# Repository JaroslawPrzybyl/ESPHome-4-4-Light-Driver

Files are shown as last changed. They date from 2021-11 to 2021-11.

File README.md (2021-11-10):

# ESPHome-4-4-Light-Driver
**Small light controller with 4 AC SSR outputs and 4 optoisolated inputs, designed for Home Assistant.**

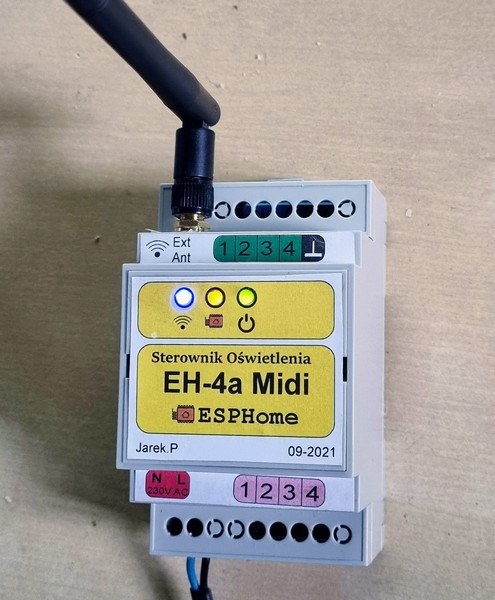
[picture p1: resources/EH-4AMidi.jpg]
EH-4A Midi

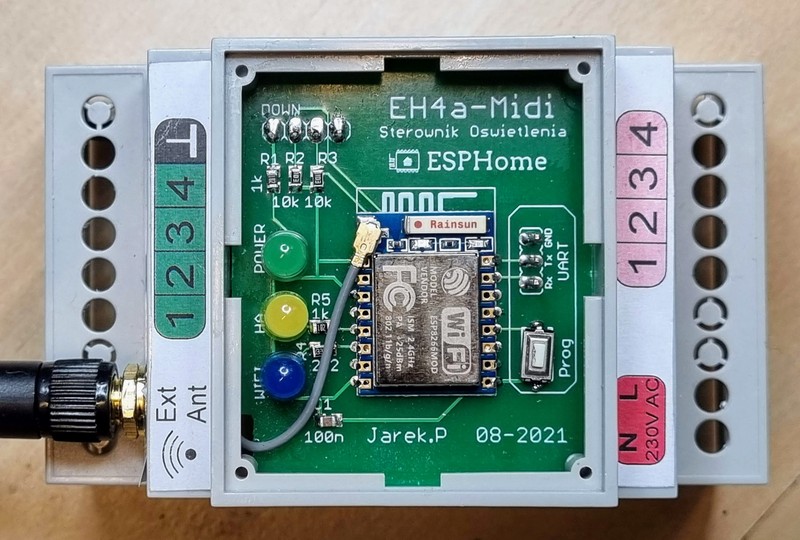
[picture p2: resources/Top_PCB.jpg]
Upper board

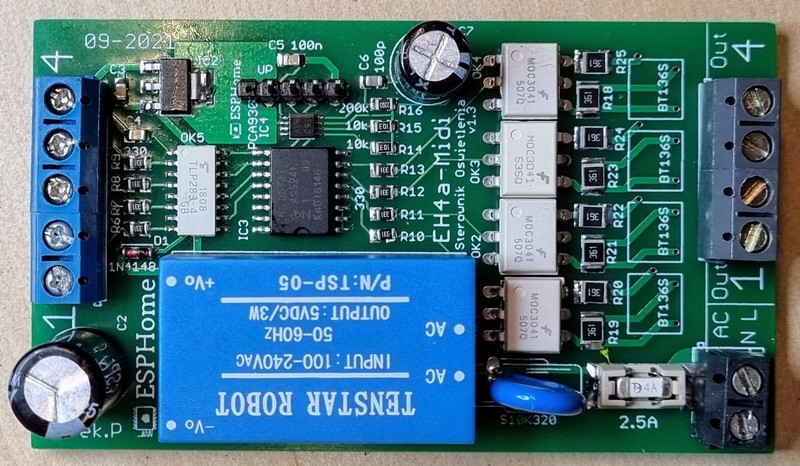
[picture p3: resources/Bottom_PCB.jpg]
Main board


## Design
Not so much to describe - just ESP with power supply and I2C expander, where four ports are used as inputs and four as outputs. Design of inputs and outputs was using by me from a years with other Home Automation systems (old stuff based on AVR CPUs, currently swapping by a bit more modern, HomeAssistant compatible devices), without any problems.  
Outputs are made as SSR relays, switched with zero-cross detection. It means safe switching of any active  load like lamps, etc, but reactive load is not allowed here, so please don't use this device with any induction load, like e.g. engines.   
Inputs are designed for use momentary buttons, each input port responds to shorting it with the COM. Needed wiring of inputs (and outputs) is shown on schematic diagram, with grey lines.  

**WARNING! Don't connect input lines with AC installation or any external power lines, it must be fully separated, only direct connections to switch buttons are allowed**   

## Parts and components
Base of this device is an ESP-07 module, choosen due to possibility to connect external antenna. If it is not needed, can be used also ESP12 or any other with the same footprint, such change has be included in the code.
All other components are listed in BoM file.   

Connection between boards can be done by any method, pins have to be connected 1:1.   
Because reverse connection will damage ESP module, I would recommend to use any connection method, which avoid of it. Connector like  Molex KK would be the best solution, any other with raster 2,54 will be also ok. On my prototype I used ordinary goldpin connector with one pin more than needed, this pin is removed and corresponding pin in the plug is blinded by glue.

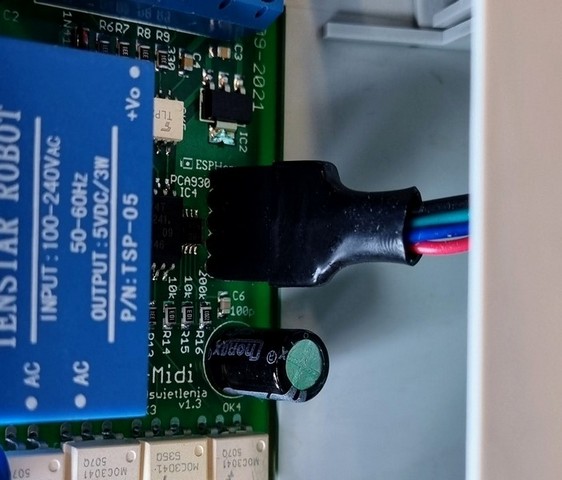
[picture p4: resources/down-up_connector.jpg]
Connector


PSU: popular chinese HLK-PM01, 5V/0.6A. AC input is protected by varistor and 4A fuse. Due to lack of space I used small fuse SMD 1808 which is not recommended to use with voltage higher than 127V - I know, but I ignored it, because this part really suited me and here important for me was to have something able to make a break in the circuit. Load will be (should be!) active, so there shouldn't be a problems with overvoltage, arcs etc. Fuse is changeable, fuses and sockets were bought on Aliexpress:

https://www.aliexpress.com/item/32840204422.html

Terminal ports - I used old spare, which I had in my draver, but any with raster 5.08mm can be used here. Or - if needed, popular "green" sepparable Phoenix terminal blocks should fit here also.

## Assembly

PCB Gerber files are attached. It is not exactly the same version as shown on photos, it was a prototype, after I did some cosmetic corrections and here I put a final version.  
Both PCBs are prepared for standard DIN rail box case Gainta D3MG http://www.gainta.com/en/d3mg.html, nothing more is needed for assembly, both PCBs fit into the latches inside the case.    
External antena is optional, you can use it or stay with internal - up to you. When device is mounted inside of metal switchbox, external antenna mounted outside of box is strongly recommended.  
Stickers should be printed on self-adhesive paper or foil. In my projects I'm using self-adhesive printable white or silver foil, special for laser printers.   

## Software

From ESP-Home perspective it is really simple device, shouldn't be any problems with the code. The only important thing which should be pointed out is that when you use ESP-07, its integration in ESPHome contains a bug, which is not corrected from the years (was reported many times as I know, without any result). So in declaration of board type, instead of esp_07, has to be used esp01_1m and with this workaround everything works fine.  
Basic proposal of code is added into the files, each input controls its corresponding output, where "short" click on the button just switch on or off the output, "long" click (press and hold more than 1s) switches off all outputs (really useful option for fast switching off the lights in the room). Clicks shorter than 50ms are ignored (debouncing), longer than 5s are also ignored (could be additionally reported as a short circuit on the line, it is not included in this code, but can be simply done).   
Only line 4 works a bit different, here is implemented a timer: short click switches on Out4  for 30 seconds (time value is set as at the top of code), after this time output  will be switched off. Each time it can be switched off manually by click the button again. And long click here works differently: it switches on the output permanently (until switching off by pressing button). 

Exemplary entity works with this code (entity code added into files):

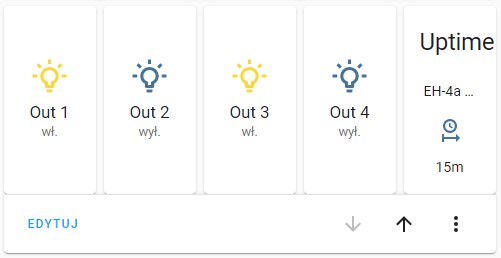
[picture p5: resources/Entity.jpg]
Entity


##  



Shield: [][cc-by-nc-sa]

This work is licensed under a
[Creative Commons Attribution-NonCommercial-ShareAlike 4.0 International License][cc-by-nc-sa].

[][cc-by-nc-sa]

[cc-by-nc-sa]: http://creativecommons.org/licenses/by-nc-sa/4.0/
[cc-by-nc-sa-image]: https://licensebuttons.net/l/by-nc-sa/4.0/88x31.png
[cc-by-nc-sa-shield]: https://img.shields.io/badge/License-CC%20BY--NC--SA%204.0-lightgrey.svg

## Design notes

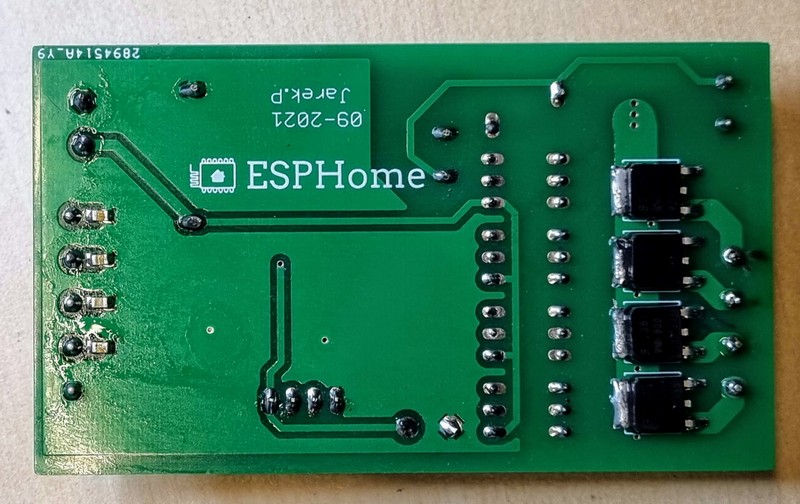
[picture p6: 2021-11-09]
resources/Triacs.jpg

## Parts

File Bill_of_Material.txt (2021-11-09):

Part    Value   Device               Package            Description
C1      100n    C-EUC0805            C0805
C2      470u    CPOL-EUE3.5-8        E3,5-8
C3      100n    C-EUC0805            C0805
C4      100n    C-EUC0805            C0805
C5      100n    C-EUC0805            C0805
C6      100p    C-EUC0805            C0805
C7      220u    CPOL-EUE2.5-7        E2,5-7
C100    100n    C-EUC0805            C0805
C101    100n    C-EUC0805            C0805
C102    100n    C-EUC0805            C0805
C103    100n    C-EUC0805            C0805
D1      1N5819  DIODESOD-123         SOD-123            Can be any other Shottky.
DOWN            PINHD-1X4            1X04               PIN HEADER
F1      4A      2920L700SL           2920L              SMD1808 fuse socket with fuse 4A
HA              LED3MM               LED3MM             LED 5mm Orange
IC1     ESP8266-ESP-07               ESP12              ESP8266 Wifi module
IC2     LD117A  LD117AS12TR          SOT223
IC3     PCF8574TPCF8574T             SO16W
IC4     PCA9306 IC2_LEVEL_TRANSLATER MSOP08
OK1     MOC3041 IL420                DIL06
OK2     MOC3041 IL420                DIL06
OK3     MOC3041 IL420                DIL06
OK4     MOC3041 IL420                DIL06
OK5     TLP283-4TLP283-4             MINI-FLAT-16
POWER           LED3MM               LED3MM             LED 5mm Green
R1      820     R-EU_M0805           M0805
R2      10k     R-EU_M0805           M0805
R3      10k     R-EU_M0805           M0805
R4      3k3     R-EU_M0805           M0805
R5      820     R-EU_M0805           M0805
R6      330     R-EU_M0805           M0805
R7      330     R-EU_M0805           M0805
R8      330     R-EU_M0805           M0805
R9      330     R-EU_M0805           M0805
R10     330     R-EU_M0805           M0805
R11     330     R-EU_M0805           M0805
R12     330     R-EU_M0805           M0805
R13     330     R-EU_M0805           M0805
R14     10k     R-EU_R0805           R0805
R15     10k     R-EU_R0805           R0805
R16     200k    R-EU_R0805           R0805
R17     S10K300 S10K300              S10K300            VARISTOR
R18     330     R-EU_R1210           R1210
R19     330     R-EU_R1210           R1210
R20     360     R-EU_R1210           R1210
R21     330     R-EU_R1210           R1210
R22     360     R-EU_R1210           R1210
R23     330     R-EU_R1210           R1210
R24     360     R-EU_R1210           R1210
R25     360     R-EU_R1210           R1210
S1      Prog    DTSM-3               DTSM-3				SMD mountable tact switch
T100    BT136S  ACT108WDPAK          SOT428
T101    BT136S  ACT108WDPAK          SOT428
T102    BT136S  ACT108WDPAK          SOT428
T103    BT136S  ACT108WDPAK          SOT428
U1      HLK-05PMHLK-PM01_HLK-PM01    HLK-PM01_HLK-PM01  HLK-PM05
UART            JP2E                 JP2                JUMPER
UP              PINHD-1X4            1X04               PIN HEADER
WIFI            LED3MM               LED3MM             LED 5mm Blue
X1      MKDSN1,5MKDSN1,5/5-5,08      MKDSN1,5/5-5,08
X2      230V AC MKDSN1,5/2-5,08      MKDSN1,5/2-5,08
X3      MKDSN1,5MKDSN1,5/4-5,08      MKDSN1,5/4-5,08

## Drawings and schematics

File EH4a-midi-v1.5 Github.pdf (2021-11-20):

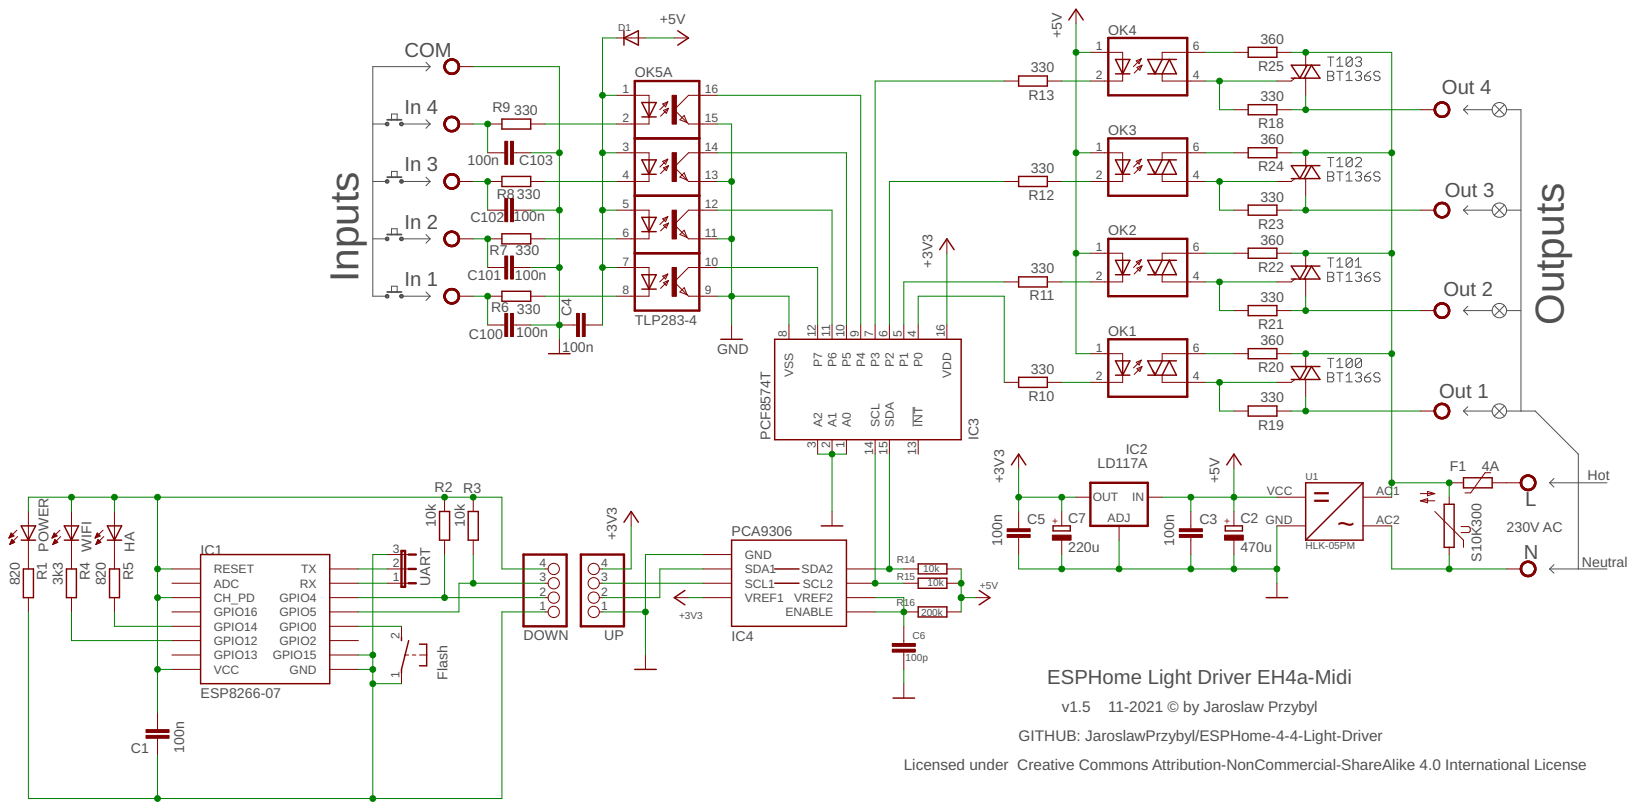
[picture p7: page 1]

GITHUB: JaroslawPrzybyl/ESPHome-4-4-Light-Driver Licensed under Creative Commons Attribution-NonCommercial-ShareAlike 4.0 International License

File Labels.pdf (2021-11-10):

## EH-4a Midi

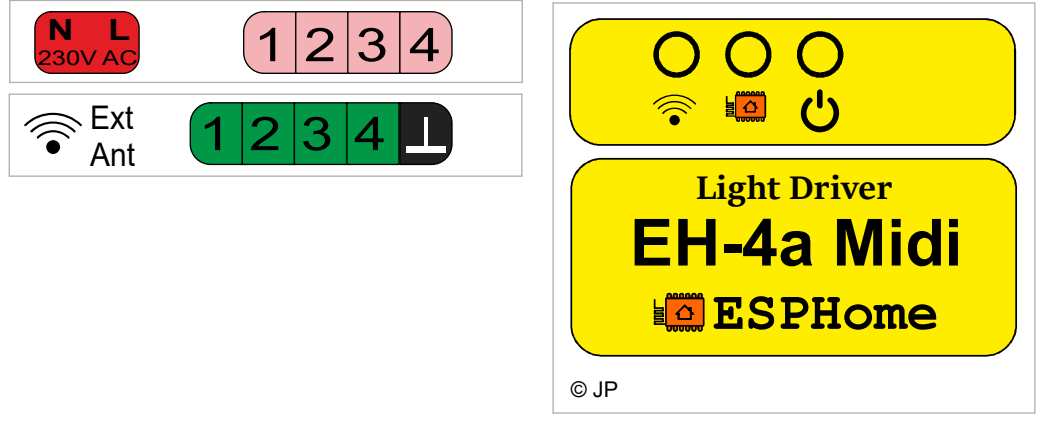
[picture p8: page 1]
1 2 3 4 Ext Ant; Light Driver; ESPHome

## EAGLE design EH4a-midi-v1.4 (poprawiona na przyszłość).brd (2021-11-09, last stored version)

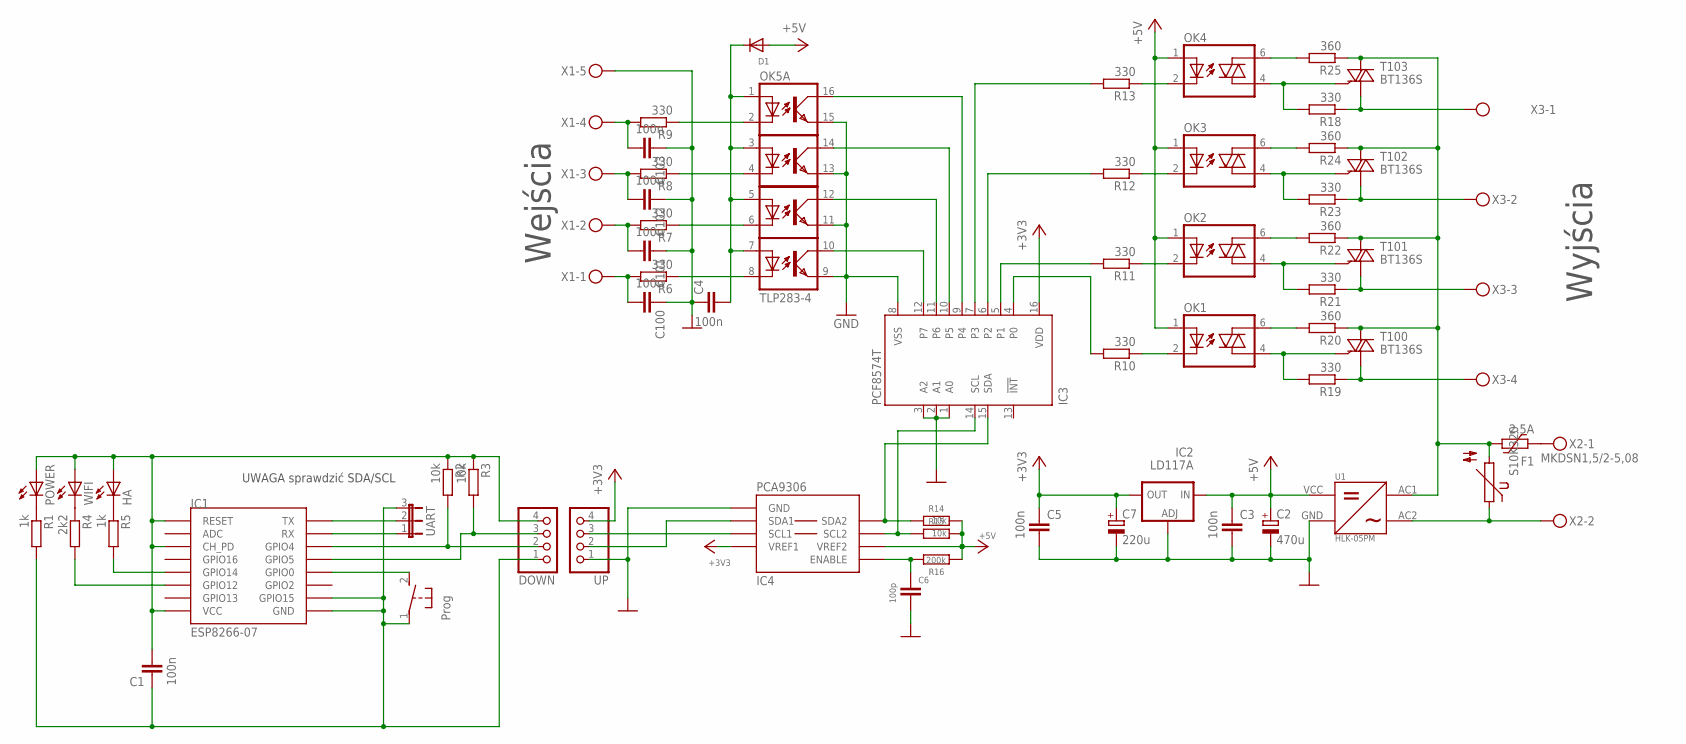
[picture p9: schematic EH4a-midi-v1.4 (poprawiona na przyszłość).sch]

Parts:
C1, C3, C4, C5, C100, C101, C102, C103: 100n; C0805
C2: 470u; E3,5-8
C6: 100p; C0805
C7: 220u; E2,5-7
D1: 1N4148; SOD-123
DOWN: PINHD-1X4; 1X04
F1: 2.5A; 2920L
HA: LED3MM
IC1: ESP8266-07; ESP12
IC2: LD117A; SOT223
IC3: PCF8574T; SO16W
IC4: PCA9306; MSOP08
OK1: MOC3043; DIL06
OK2, OK3, OK4: IL420; DIL06
OK5: TLP283-4; MINI-FLAT-16
POWER: LED3MM
R1, R5: 1k; M0805
R2, R3: 10k; M0805
R4: 2k2; M0805
R6, R7, R8, R9, R10, R11, R12, R13: 330; M0805
R14, R15: 10k; R0805
R16: 200k; R0805
R17: S10K320
R18, R19, R21, R23: 330; R1210
R20, R22, R24, R25: 360; R1210
S1: Prog; DTSM-3
T100, T101, T102, T103: BT136S; SOT428
U1: HLK-05PM; HLK-PM01_HLK-PM01
UART: JP2E; JP2
UP: PINHD-1X4; 1X04
WIFI: LED3MM
X1: MKDSN1,5/5-5,08
X2: MKDSN1,5/2-5,08
X3: MKDSN1,5/4-5,08

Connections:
3V3: C1.2, DOWN.4, HA.A, IC1.CH_PD, IC1.RESET, IC1.VCC, POWER.A, R2.1, R3.1, WIFI.A
+3V3: C5.1, C7.+, IC2.2 (OUT), IC2.4 (OUT), IC3.16 (VDD), IC4.2 (VREF1), UP.4
+5V: C2.+, C3.1, D1.A, IC2.3 (IN), IC4.7 (VREF2), OK1.1 (A), OK2.1 (A), OK3.1 (A), OK4.1 (A), R14.1, R15.1, R16.2, U1.VCC
GND: C2.-, C3.2, C4.1, C5.2, C6.2, C7.-, C100.1, C101.1, C102.1, C103.1, IC2.1 (ADJ), IC3.1 (A0), IC3.2 (A1), IC3.3 (A2), IC3.8 (VSS), IC4.1 (GND), OK5.9 (EMIT), OK5.11 (EMIT), OK5.13 (EMIT), OK5.15 (EMIT), U1.GND, UP.1, X1.5
GND1: C1.1, DOWN.1, IC1.GND, IC1.GPIO15, R1.2, S1.1, UART.3
L: F1.1, R17.2, R20.1, R22.1, R24.1, R25.1, T100.MB (LD), T101.MB (LD), T102.MB (LD), T103.MB (LD), U1.AC1
unnamed: IC3.7 (P3), R13.2
unnamed: IC3.10 (P5), OK5.14 (COL)
unnamed: IC3.11 (P6), OK5.12 (COL)
unnamed: IC3.12 (P7), OK5.10 (COL)
unnamed: IC3.6 (P2), R12.2
unnamed: OK4.2 (C), R13.1
unnamed: OK1.2 (C), R10.1
unnamed: OK2.2 (C), R11.1
unnamed: IC3.5 (P1), R11.2
unnamed: IC3.4 (P0), R10.2
unnamed: IC1.GPIO14, R5.2
unnamed: R17.1, U1.AC2, X2.2
unnamed: C103.2, R9.2, X1.4
unnamed: C102.2, R8.2, X1.3
unnamed: F1.2, X2.1
unnamed: POWER.K (C), R1.1
unnamed: R4.1, WIFI.K (C)
unnamed: HA.K (C), R5.1
unnamed: IC1.GPIO12, R4.2
unnamed: IC1.GPIO0, S1.2
unnamed: IC1.RX, UART.1
unnamed: IC1.TX, UART.2
unnamed: C6.1, IC4.8 (ENABLE), R16.1
unnamed: IC3.9 (P4), OK5.16 (COL)
unnamed: OK3.2 (C), R12.1
unnamed: C4.2, D1.C, OK5.1 (A), OK5.3 (A), OK5.5 (A), OK5.7 (A)
unnamed: OK5.2 (C), R9.1
unnamed: OK5.4 (C), R8.1
unnamed: OK5.6 (C), R7.1
unnamed: OK5.8 (C), R6.1
unnamed: OK1.4 (A1), R19.2, T100.3 (G)
unnamed: R19.1, T100.1 (CM), X3.4
unnamed: C101.2, R7.2, X1.2
unnamed: C100.2, R6.2, X1.1
unnamed: OK2.4 (A1), R21.2, T101.3 (G)
unnamed: R21.1, T101.1 (CM), X3.3
unnamed: OK3.4 (A1), R23.2, T102.3 (G)
unnamed: R23.1, T102.1 (CM), X3.2
unnamed: OK4.4 (A1), R18.2, T103.3 (G)
unnamed: R18.1, T103.1 (CM), X3.1
unnamed: OK4.6 (A2), R25.2
unnamed: OK3.6 (A2), R24.2
unnamed: OK2.6 (A2), R22.2
unnamed: OK1.6 (A2), R20.2
SCL: IC3.14 (SCL), IC4.6 (SCL2), R15.2
SCL1: DOWN.3, IC1.GPIO5, R3.2
SCL': IC4.3 (SCL1), UP.3
SDA: IC3.15 (SDA), IC4.5 (SDA2), R14.2
SDA1: DOWN.2, IC1.GPIO4, R2.2
SDA': IC4.4 (SDA1), UP.2

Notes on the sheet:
Wejścia
Wyjścia
UWAGA sprawdzić SDA/SCL

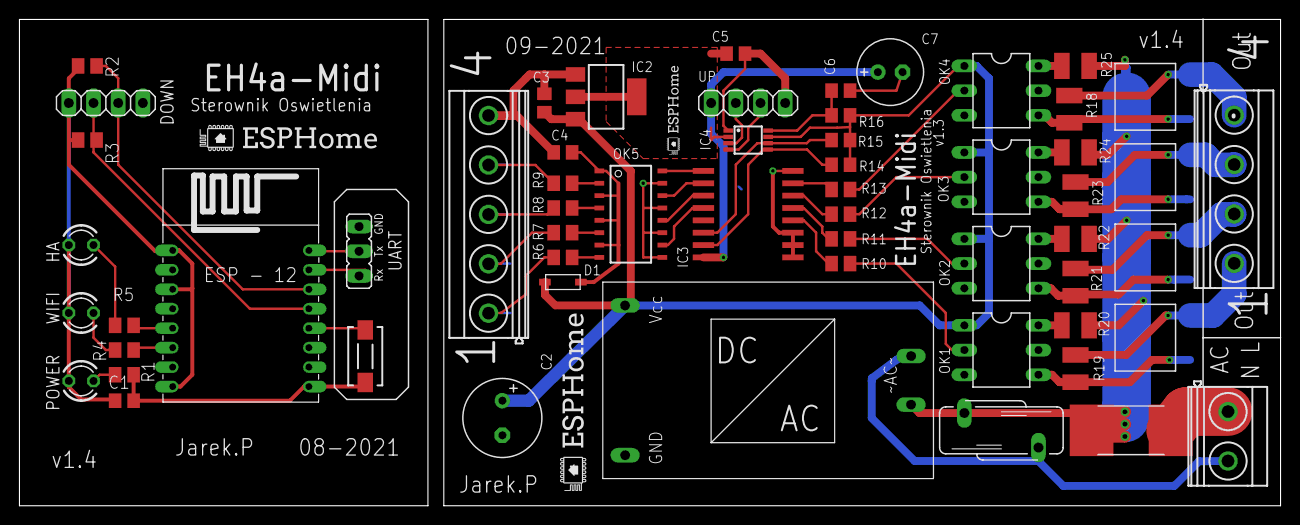
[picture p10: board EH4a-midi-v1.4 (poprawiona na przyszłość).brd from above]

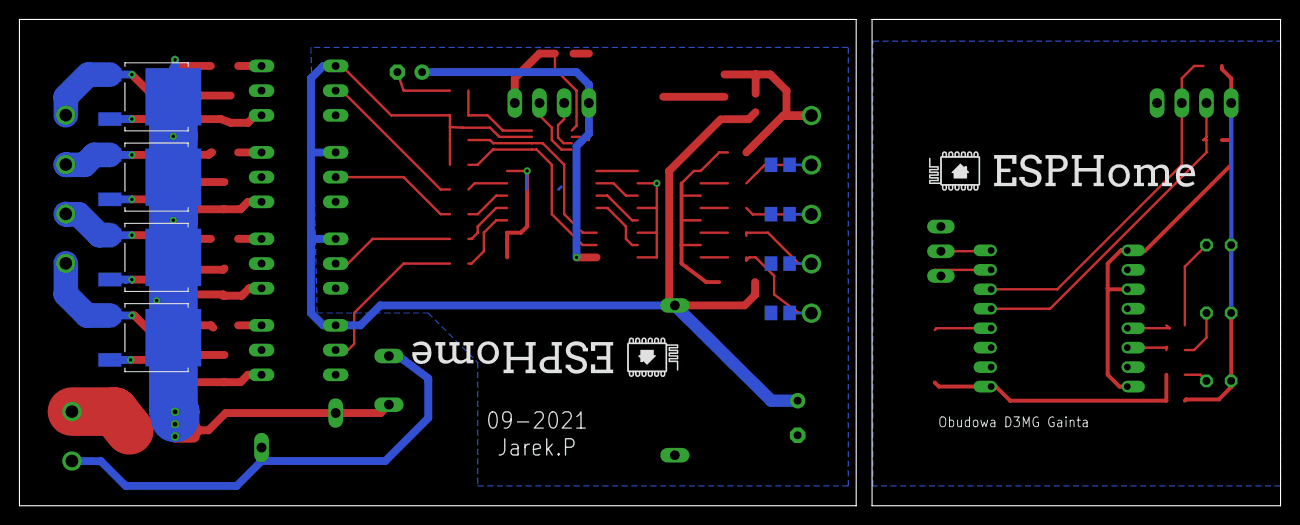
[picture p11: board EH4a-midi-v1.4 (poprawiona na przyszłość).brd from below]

Board: 2 copper layers, 129.7 x 50.0 mm, 62 parts (8 on the bottom side), 56 nets.

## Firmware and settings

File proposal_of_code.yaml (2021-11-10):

######################################
#                                    #
# Proposal of code for light driver  #
#         Jarek.P 11-2021            #
#                                    #
######################################

substitutions:
  Out4_time: "30s" 

esphome:
  name: eh-4a_midi_test
  platform: ESP8266
  board: esp01_1m
  comment: Simple light driver EH-4a Midi
  on_loop: #in this loop wifi connection is checked
    if:
        condition:
            wifi.connected:
        then:
            lambda: !lambda |-
              if not (id(wifi_led).state) {
                
              } else {
                id(wifi_led).turn_on();
              }
        else:
            lambda: !lambda |-
              if (id(wifi_led).state) {
                id(wifi_led).turn_on();
              } 

wifi:
  ssid: "Your_WIFI_SSID"
  password: "Your_wifi_key"
  manual_ip: #this section can be removed for enabling DHCP
    static_ip: 10.1.1.44
    gateway: 10.1.1.1
    subnet: 255.255.255.0

  # Enable fallback hotspot (captive portal) in case wifi connection fails
  ap:
    ssid: "Eh-4A Midi Test Fallback Hotspot"
    password: "secret_password"

captive_portal:

# Enable logging
logger:

# Enable Home Assistant API
api:
  password: "secret_password"

ota:
  password: "secret_password"

i2c:
  sda: 5
  scl: 4

pcf8574:
  - id: 'pcf'
    address: 32 
    pcf8575: False    

text_sensor: #uptime outputhor humans
  - platform: template
    name: EH-4a Uptime 
    id: uptime_human
    icon: mdi:clock-start

sensor: #calculating of uptime to human readable format
  - platform: uptime
    name: Uptime Sensor
    id: uptime_sensor
    on_raw_value:
      then:
        - text_sensor.template.publish:
            id: uptime_human
            state: !lambda |-
              int seconds = round(id(uptime_sensor).raw_state);
              int days = seconds / (24 * 3600);
              seconds = seconds % (24 * 3600);
              int hours = seconds / 3600;
              seconds = seconds % 3600;
              int minutes = seconds / 60;
              seconds = seconds % 60;
              return (
                (days ? String(days) + "d " : "") +
                (hours ? String(hours) + "h " : "") +
                (minutes ? String(minutes) + "m " : "")
              ).c_str();


binary_sensor: #status of connection to HA server
  - platform: status
    id: api_status
    internal: yes
    on_state:
      then:
        - switch.turn_on: status_led
    on_release:
      then:
        - switch.turn_off: status_led

########################
##       INPUTS       ##
########################

  - platform: gpio 
    name: "EH4a - In1"
    id: In1
    pin:
      pcf8574: pcf
      number: 7
      mode: INPUT
      inverted: True 
    filters:
      - delayed_on_off: 50ms      
    on_click:
    - min_length: 50ms
      max_length: 1000ms
      then:
        - switch.toggle: Out_1
    - min_length: 1000ms
      max_length: 5000ms
      then:
        - switch.turn_off: Out_1      
        - switch.turn_off: Out_2      
        - switch.turn_off: Out_3      
        - switch.turn_off: Out_4      

  - platform: gpio 
    name: "EH4a - In2"
    id: In2
    pin:
      pcf8574: pcf
      number: 6
      mode: INPUT
      inverted: True 
    filters:
      - delayed_on_off: 50ms      
    on_click:
    - min_length: 50ms
      max_length: 1000ms
      then:
        - switch.toggle: Out_2
    - min_length: 1000ms
      max_length: 5000ms
      then:
        - switch.turn_off: Out_1      
        - switch.turn_off: Out_2      
        - switch.turn_off: Out_3      
        - switch.turn_off: Out_4      

  - platform: gpio 
    name: "EH4a - In3"
    id: In3
    pin:
      pcf8574: pcf
      number: 5
      mode: INPUT
      inverted: True 
    filters:
      - delayed_on_off: 50ms      
    on_click:
    - min_length: 50ms
      max_length: 1000ms
      then:
        - switch.toggle: Out_3
    - min_length: 1000ms
      max_length: 5000ms
      then:
        - switch.turn_off: Out_1      
        - switch.turn_off: Out_2      
        - switch.turn_off: Out_3      
        - switch.turn_off: Out_4      

  - platform: gpio 
    name: "EH4a - In4"
    id: In4
    pin:
      pcf8574: pcf
      number: 4
      mode: INPUT
      inverted: True 
    filters:
      - delayed_on_off: 50ms      
    on_click:
    - min_length: 50ms
      max_length: 1000ms
      then:
        - if:
            condition:
                - switch.is_on: Out_4
            then:
                - switch.turn_off: Out_4
                - script.stop: timer_Out_4
            else:
                - script.execute: timer_Out_4
    - min_length: 1000ms
      max_length: 5000ms
      then:
        - script.stop: timer_Out_4
        - switch.turn_on: Out_4      
#end of inputs
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

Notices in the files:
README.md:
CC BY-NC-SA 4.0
